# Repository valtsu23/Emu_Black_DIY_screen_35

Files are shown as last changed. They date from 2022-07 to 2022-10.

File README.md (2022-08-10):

# Emu_Black_DIY_screen_35
Microcontroller reading sensor values from can bus and sending them to LCD screen. Also equipped with shift light and light sensor to control screen and shift light brightness. Also supports errorflags. It shows amount of errors and name of the first two errors. 


### Parts used (total about 130€):
- Adafruit Feather M4 CAN Express with ATSAME51
- Adafruit DS3231 Precision RTC Breakout (blue one)
- NeoPixel Stick - 8 x 5050 RGB LED
- MPM3610 5V 1.2A Buck Converter Breakout
- Nextion Discovery 3.5" (NX4832F035)
- CR1220 battery
- pcb own desing (from JLCPCB)
- JST-SM 4pin connector pair
- JST-XH female connector
- 2A fast diode
- tantalum capacitor 0,47µF 35V
- 1kohm 0,6W resistor
- photoresistor 200R - 500K
- side actuated tactile switch (TE 1-1825027-1)
- 1row 90 degree pin header 2,54mm
- 2 pin DuPont style housing
- 3 pin DuPont style housing
- 0,22mm2 stranded wire (24 AWG)
- 4x M3x5 button head screws
- 4x M3x10 countersunk screws
- 2x M3x8 countersunk screws
- magnetic car phone holder
- micro SD-card for uploading file to Nextion
- case printed from PETG with Creality Ender 3 V2

### Assembly:
One modification is needed for the Feather: Remove resistor next to the EN-pin (R8 on schematic). This disables the battery charger chip and then you can use the BAT-pin for 5v input. With this modification done you can connect it to computer with auxiliar power supply without worries. 
I had to drill bigger mounting holes to the Nextion to rotate the screen slightly, because screen wasn't installed straight to the pcb. Hot glue is used to the photoresistor. 

### Setup
Check Adafruit guide for setting up the Feather. Upload HMI file to sd card and Nextion will upload it when powered, then remove sd card. 
You also need to change the  baudrate to 115200 with code.py. Shift light setup guide is in the code.py. 

### Video of the shift light action
https://youtu.be/XviCfcwE8Wc

### Conclusion
The screen brightness is ok, but still could be brighter. Using black and white colours does help in the sunlight. 
Otherwise it has been working well. Early days still. 

### Pictures

Pcb on this picture is earlier prototype. Feather had a faulty voltage booster so I had to delete it. 
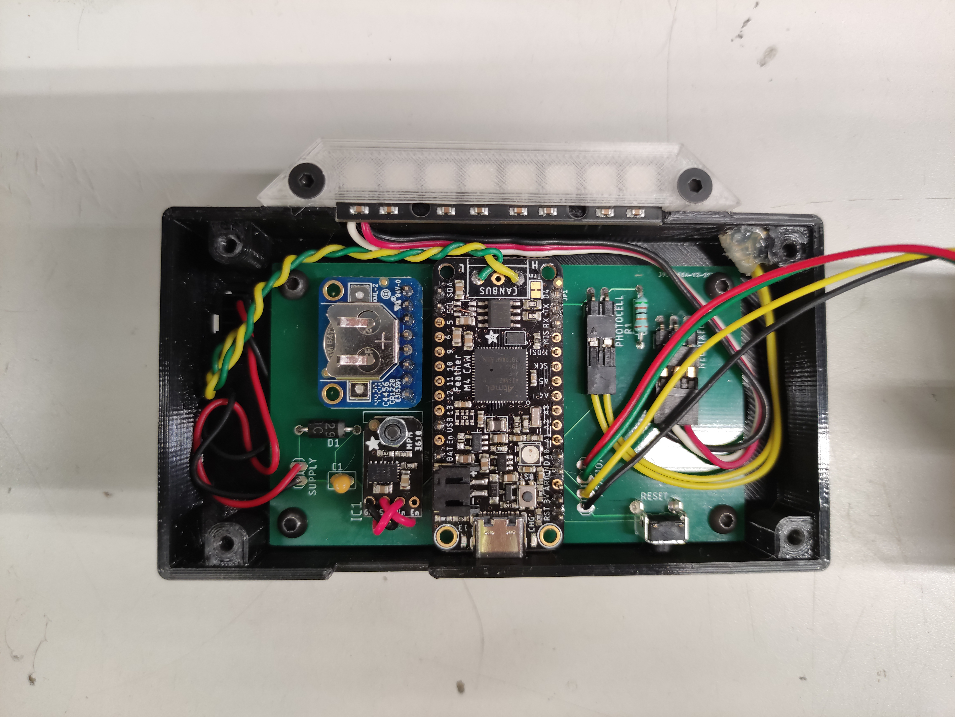
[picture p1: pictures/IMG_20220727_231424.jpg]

New one:
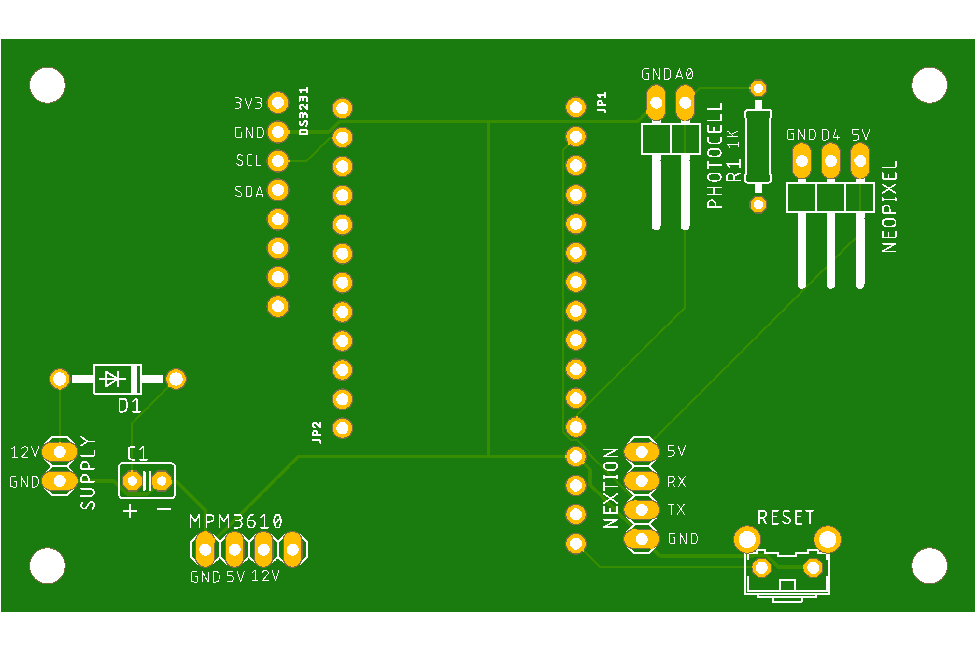
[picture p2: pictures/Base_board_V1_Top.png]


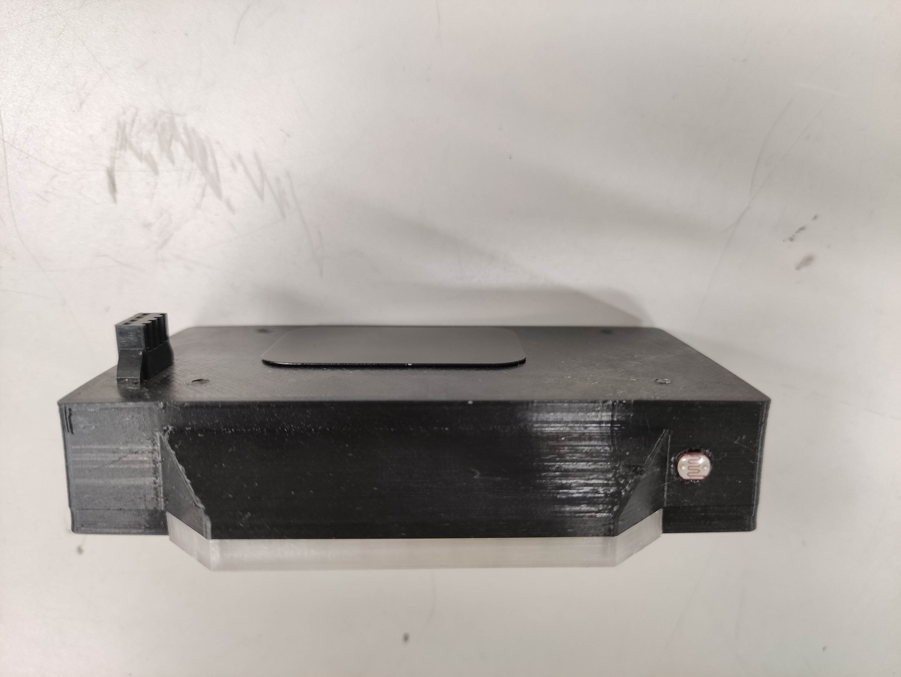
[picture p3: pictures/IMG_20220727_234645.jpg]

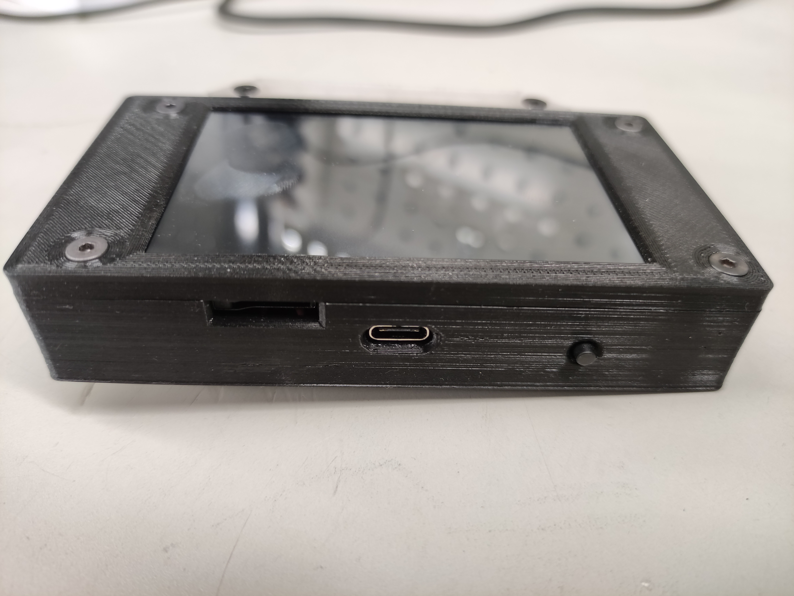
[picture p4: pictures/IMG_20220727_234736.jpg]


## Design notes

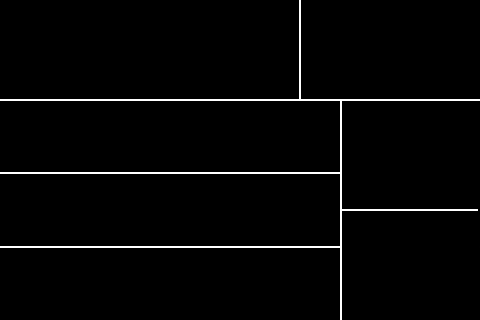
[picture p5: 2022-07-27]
Background.png

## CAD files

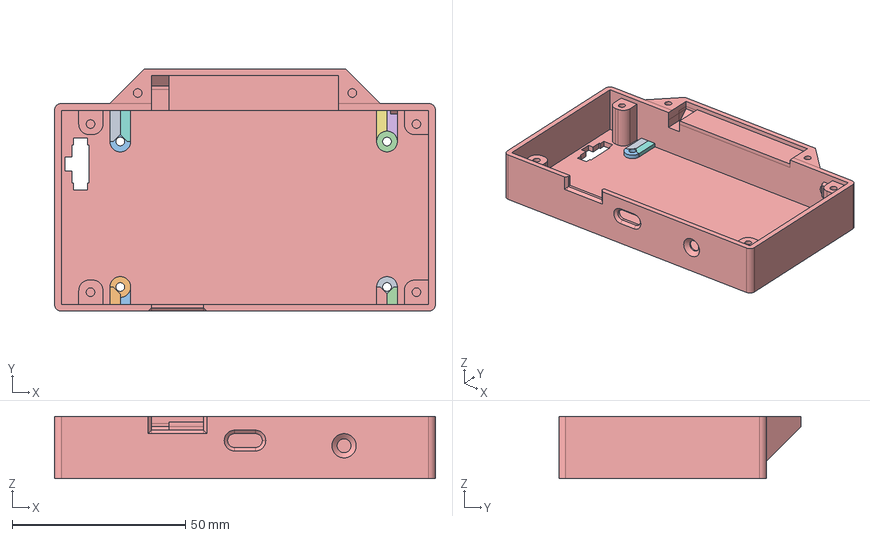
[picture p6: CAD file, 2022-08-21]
3d_print/Case.FCStd
110.0 x 70.0 x 18.0 mm
Tube
Tube001
Tube002
Tube003

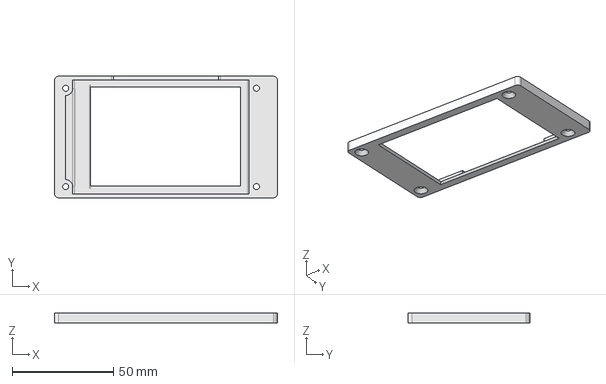
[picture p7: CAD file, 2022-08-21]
3d_print/Top1.FCStd
110.0 x 60.0 x 5.00 mm

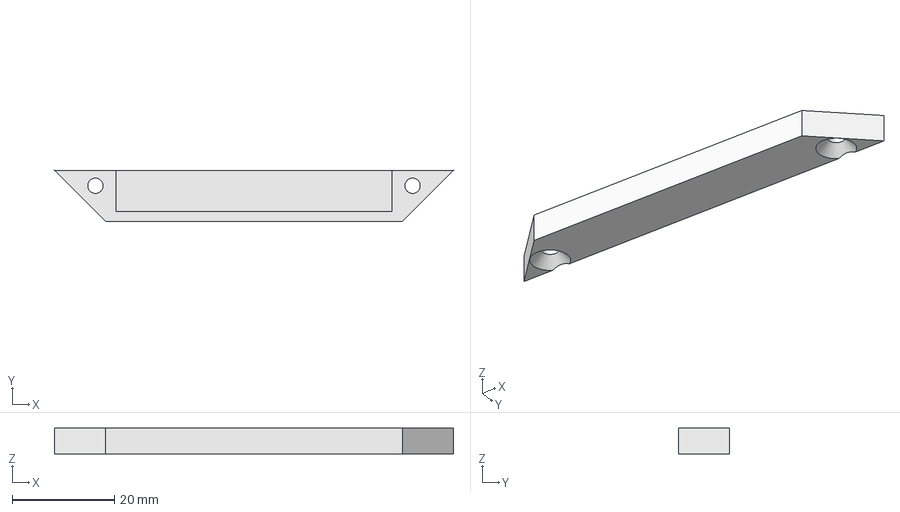
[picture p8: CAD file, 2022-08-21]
3d_print/Top2.FCStd
78.0 x 10.0 x 5.00 mm

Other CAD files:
3d_print/Case.stl
3d_print/Top1.stl
3d_print/Top2.stl

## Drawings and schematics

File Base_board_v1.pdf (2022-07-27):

A

A

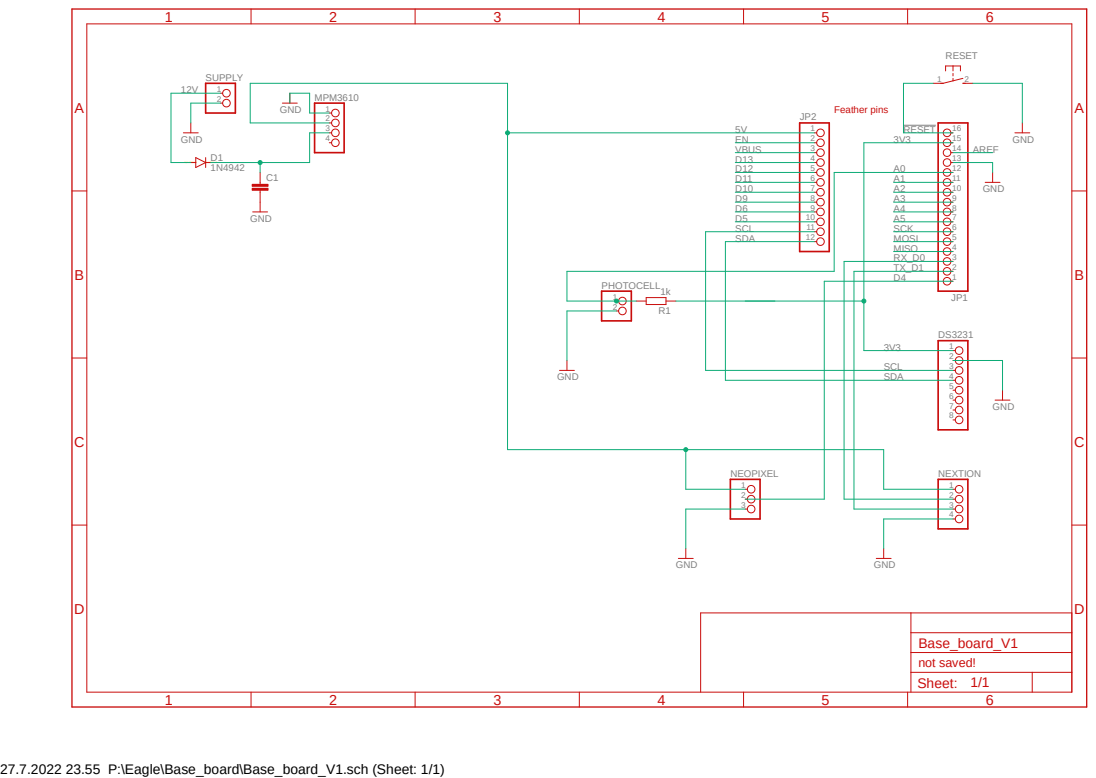
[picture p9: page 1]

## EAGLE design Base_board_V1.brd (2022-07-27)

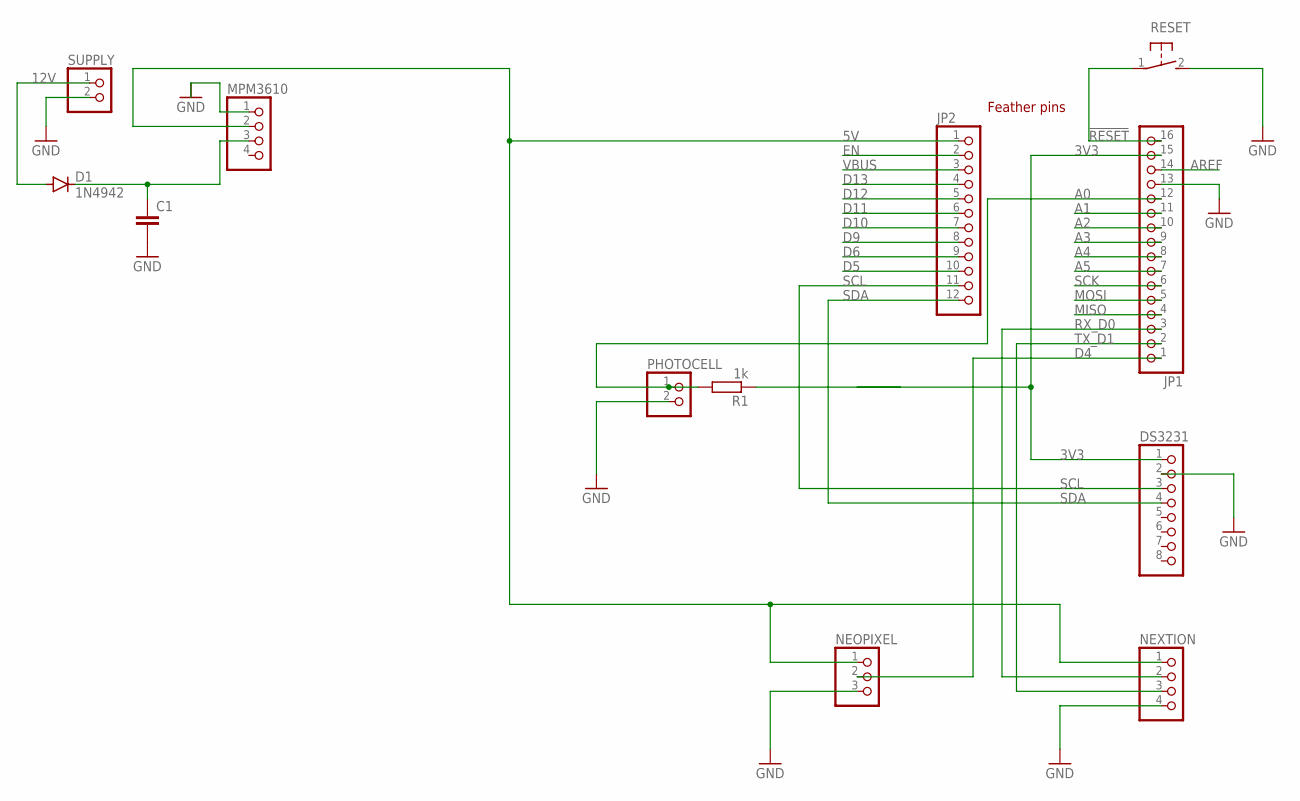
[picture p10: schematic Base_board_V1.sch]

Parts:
C1: C2,5-3; C2.5-3
D1: 1N4942; DO41-10
DS3231: HEADER-1X870MIL; 1X08_ROUND_70
JP1: HEADER-1X16ROUND; 1X16_ROUND
JP2: HEADER-1X12; 1X12_ROUND
MPM3610: PINHD-1X4; 1X04
NEOPIXEL: PINHD-1X3/90; 1X03/90
NEXTION: PINHD-1X4; 1X04
PHOTOCELL: PINHD-1X2/90; 1X02/90
R1: 1k; 0207/10
RESET: 31-XX; B3F-31XX
SUPPLY: PINHD-1X2; 1X02

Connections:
3V3: DS3231.1, JP1.15, R1.1
5V: JP2.1, MPM3610.2, NEOPIXEL.1, NEXTION.1
12V: D1.A, SUPPLY.1
!RESET: JP1.16, RESET.1
A0: JP1.12, PHOTOCELL.1, R1.2
A1: JP1.11
A2: JP1.10
A3: JP1.9
A4: JP1.8
A5: JP1.7
AREF: JP1.14
D4: JP1.1, NEOPIXEL.2
D5: JP2.10
D6: JP2.9
D9: JP2.8
D10: JP2.7
D11: JP2.6
D12: JP2.5
D13: JP2.4
EN: JP2.2
GND: C1.2, DS3231.2, JP1.13, MPM3610.1, NEOPIXEL.3, NEXTION.4, PHOTOCELL.2, RESET.2 (S), SUPPLY.2
MISO: JP1.4
MOSI: JP1.5
unnamed: C1.1, D1.C, MPM3610.3
RX_D0: JP1.3, NEXTION.2
SCK: JP1.6
SCL: DS3231.3, JP2.11
SDA: DS3231.4, JP2.12
TX_D1: JP1.2, NEXTION.3
VBUS: JP2.3

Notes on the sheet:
Feather pins

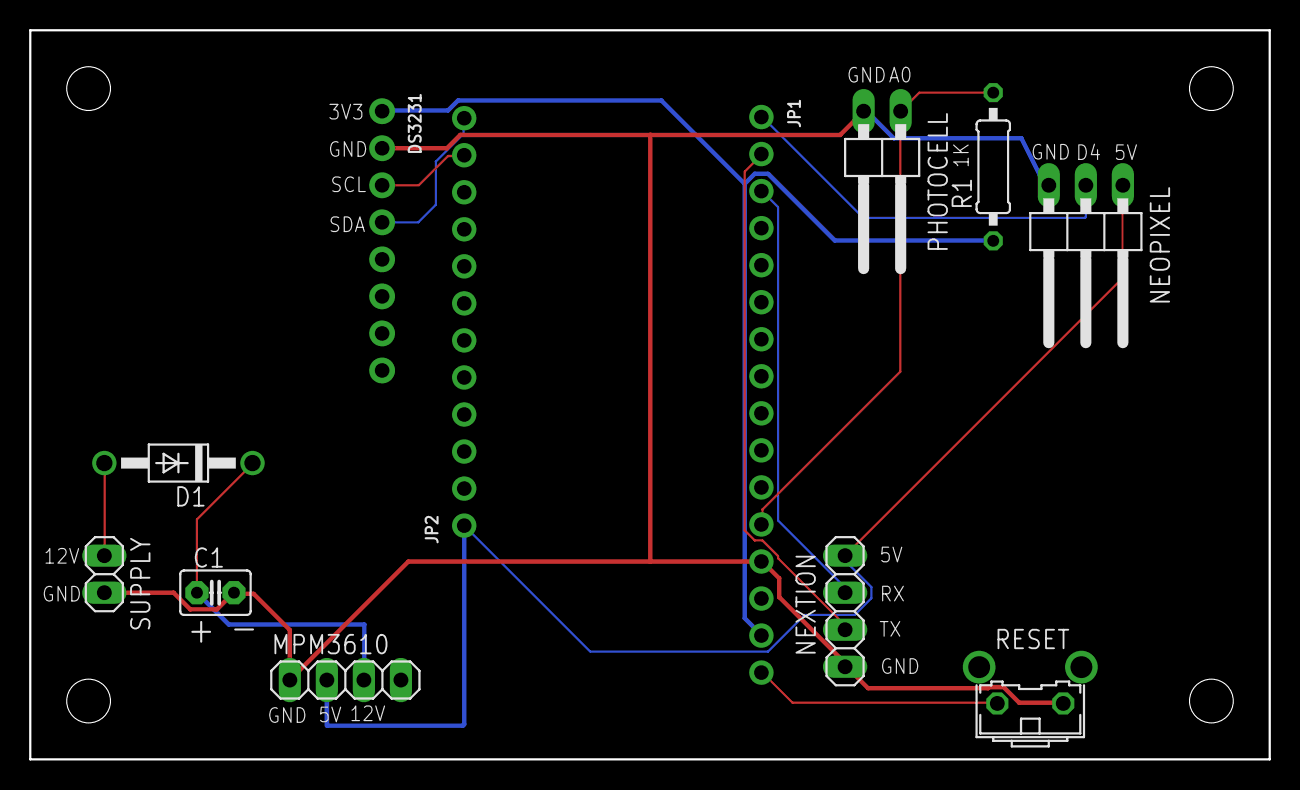
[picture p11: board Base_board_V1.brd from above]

Board: 2 copper layers, 85.0 x 50.0 mm, 12 parts (0 on the bottom side), 12 nets.

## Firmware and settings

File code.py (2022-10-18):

# Version 2.1
# - Exception Handling on I2C communication setup to prevent errors
# - Dimmer improved by slower reaction to ambient light change

import board
import busio
import time
import digitalio
import canio
import struct
import adafruit_ds3231
import analogio
import shift_light

# RTC communication
I2C_ok = False

while I2C_ok is False:
    try:
        myI2C = board.I2C()
    except RuntimeError:
        time.sleep(.1)
        print("I2C error")
    else:
        I2C_ok = True

rtc = adafruit_ds3231.DS3231(myI2C)

if False:   # change to True if you want to write the time!
    #                     year, mon, date, hour, min, sec, wday, yday, isdst
    t = time.struct_time((2021,  3,   16,   10,  30,  00,    0,   -1,    -1))
    # you must set year, mon, date, hour, min, sec and weekday
    # yearday is not supported, isdst can be set but
    # we don't do anything with it at this time

    print('Setting time to:', t)     # uncomment for debugging
    rtc.datetime = t
    print()

# UART settings
# uart = busio.UART(board.TX, board.RX, baudrate=9600, timeout=1)
uart = busio.UART(board.TX, board.RX, baudrate=115200, timeout=1)

# Message sending to Nextion
def message_send(message):
    ending = 0xFF, 0xFF, 0xFF
    uart.write(message.encode('ascii'))
    uart.write(bytes(ending))

# Nextion baudrate change
if False:
    # To make sure Nextion is ready
    time.sleep(1)
    message_send('bauds=115200')

# Error flags
ERRORFLAGS = ("", "OILP", "EWG", "DSG", "DIFFCTRL", "FPR", "DBW", "FF_SENSOR",
              "KNOCKING", "EGT_ALARM", "EGT2", "EGT1", "WBO", "MAP", "IAT", "CLT")
def error_flags(number):
    # Convert to bit list
    bit_list = [x - ord("0") for x in b"{:016b}".format(number)]
    # To boolean
    boolean = list(map(bool, bit_list))
    # Get the errors that are on
    errors_on = []
    for x in range(len(boolean)):
        if boolean[x] is True:
            errors_on.append(ERRORFLAGS[x])
    print(errors_on)
    # Send error count
    data_s = 'er_c.val=' + str(len(errors_on))
    message_send(data_s)
    # Send error codes
    if len(errors_on) == 1:
        message_send('er_1.txt=' + '"' + errors_on[0] + '"')
    elif len(errors_on) > 1:
        message_send('er_1.txt=' + '"' + errors_on[0] + '"')
        message_send('er_2.txt=' + '"' + errors_on[1] + '"')

# Light sensor
ADC = analogio.AnalogIn(board.A0)
def is_dark():
    a_val = ADC.value
    # print(a_val)
    if a_val > 35000:
        return True
    else:
        return False

# dimmer
def dimmer(value):
    global led_br
    # Dark
    if value is True:
        message_send('dim=50')
        led_br = 20
        # print("dim=50")
    # Bright
    else:
        message_send('dim=100')
        led_br = 80
        # print("dim=100")

# Run at startup
dimmer(is_dark())

# CAN BUS
# The CAN transceiver has a standby pin, bring it out of standby mode
if hasattr(board, 'CAN_STANDBY'):
    standby = digitalio.DigitalInOut(board.CAN_STANDBY)
    standby.switch_to_output(False)

# The CAN transceiver is powered by a boost converter, turn on its supply
# if hasattr(board, 'BOOST_ENABLE'):
#    boost_enable = digitalio.DigitalInOut(board.BOOST_ENABLE)
#    boost_enable.switch_to_output(True)

# Can Bus pins
can = canio.CAN(rx=board.CAN_RX, tx=board.CAN_TX, baudrate=500_000, auto_restart=True)

# CAN listener 0x600 - 0x607
listener = can.listen(matches=[canio.Match(0x600, mask=0x608)], timeout=.9)

# Shift light
# SETUP
END = 8600
STEP = 100

# Make sure the leds are off
shift_light.leds_off()

# Needed variables
old_clock = None
timer_needed = False
old_bus_state = None
shift_light_off = False
rpm = 0
old_errors = 0
old_dark = is_dark()
t1 = time.monotonic()
dim_counter = 0
# counter = 0

while True:
    # Debug
    # counter += 1
    # if counter > 1000:
    #    break
    # rpm -= 1
    # print(rpm)

    # Uart message receiving
    receiving_data = False
    buffer = uart.in_waiting
    if buffer != 0:
        data_r = uart.read(1)
        receiving_data = True
        received = []
        received.append(data_r)

    while receiving_data is True:
        data_r = uart.read(1)
        # print("Receiving")
        if data_r == b'\xff':
            data_r = uart.read(1)
            if data_r == b'\xff':
                data_r = uart.read(1)
                if data_r == b'\xff':
                    # Message ended
                    receiving_data = False
                    if received == [b'\x00', b'\x00', b'\x00']:
                        print("Nextion Startup")
                    elif received == [b'\x88']:
                        print("Nextion Ready")
                    elif received == [b'\x1a']:
                        print("Invalid variable")
                    else:
                        print('Message: ', received)
        else:
            received.append(data_r)
    # Clock
    t = rtc.datetime
    clock = "%02d:%02d" % (t.tm_hour, t.tm_min)
    # clock = '%02d:%02d' % (5, 23)   # debugging
    if clock != old_clock:
        data_s = 'cl.txt="'+clock+'"'
        message_send(data_s)
        old_clock = clock

    # Dimmer
    dark = is_dark()

    if dark is not old_dark and time.monotonic() > t1:
        dim_counter += 1
        t1 = time.monotonic() + 0.5
    elif dark is old_dark:
        dim_counter = 0

    if dim_counter > 6:
        dimmer(dark)
        old_dark = dark

    # CAN BUS
    # Bus state information
    bus_state = can.state
    if bus_state != old_bus_state:
        print(f"Bus state changed to {bus_state}")
        old_bus_state = bus_state
    message = listener.receive()

    # Message handling
    if message is None:
        print("No message received within timeout")
        # time.sleep(1)
        continue

    data = message.data
    if len(data) != 8:
        print(f"Unusual message length {len(data)}")
        # time.sleep(1)
        continue

    id = message.id

    # Printing received messages
    # print("Received a message with id:", (hex(id)))

    if id == 0x600:
        # Unpack message
        message = struct.unpack("<HBbHH", data)
        rpm = message[0]
    elif id == 0x602:
        message = struct.unpack("<HBBBBh", data)
        # Oil temperature
        oil_t = message[2]
        # Build the message
        data_s = 'ot.val='+str(oil_t)
        # Send it to Nextion
        message_send(data_s)
        # Oil pressure
        oil_p = int(message[3] * 0.625)
        data_s = 'op.val='+str(oil_p)
        message_send(data_s)
        # Fuel pressure
        fuel_p = int(message[4] * 0.625)
        data_s = 'fp.val='+str(fuel_p)
        message_send(data_s)
    elif id == 0x603:
        message = struct.unpack("<bBBBHH", data)
        # Lambda
        lambda_value = int(message[2] * 0.78125)
        data_s = 'la.val='+str(lambda_value)
        message_send(data_s)
    elif id == 0x604:
        message = struct.unpack("<BbHHBB", data)
        # Battery voltage
        battery_v = int(message[2] * 0.27)
        data_s = 'ba.val='+str(battery_v)
        message_send(data_s)
        # Error flags
        errors = message[3]
        if errors != old_errors:
            # No errors any more
            if errors == 0:
                message_send('er_c.val=0')
            # Error found
            else:
                error_flags(errors)
            old_errors = errors

    # Shift light
    if rpm > END - STEP * 5:
        shift_light.action(rpm, STEP, END, led_br)
        shift_light_off = False
        # Make sure all leds are off
    elif rpm < END - STEP * 5 and shift_light_off is False:
        shift_light.leds_off()
        shift_light_off = True

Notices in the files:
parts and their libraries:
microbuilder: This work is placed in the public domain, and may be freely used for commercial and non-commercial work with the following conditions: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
